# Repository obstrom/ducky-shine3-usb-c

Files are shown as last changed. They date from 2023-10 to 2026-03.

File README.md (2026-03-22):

# Ducky Shine3 USB-C Mod

Unofficial USB 2.0 Type C replacement module for the Ducky Shine3 (DK9008S3) mechanical keyboard first released in 2013.

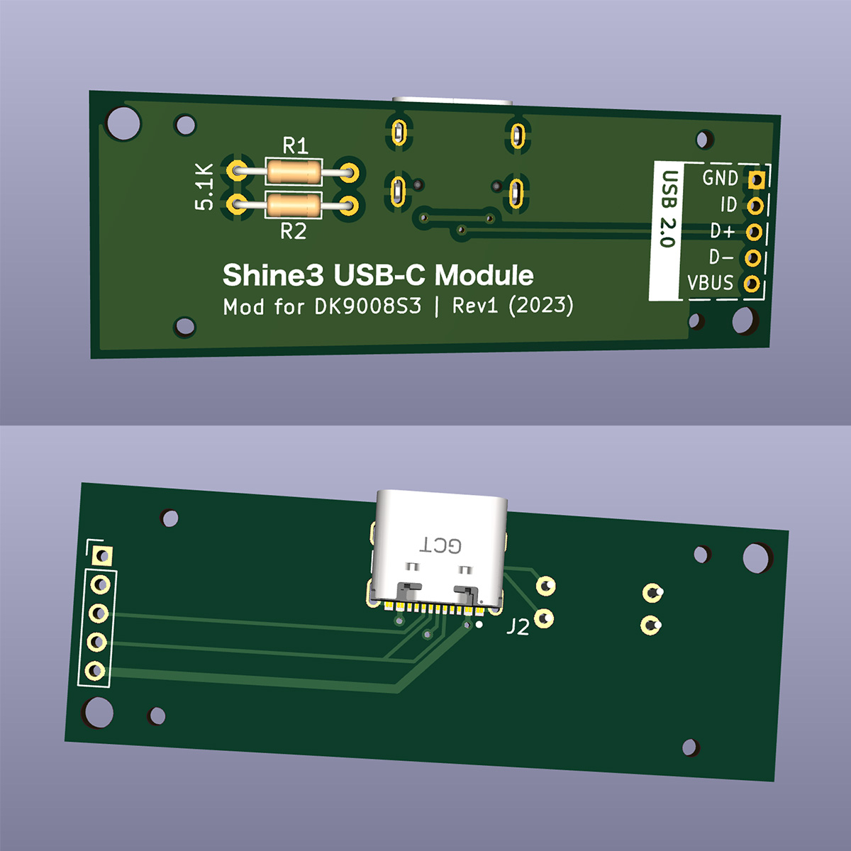
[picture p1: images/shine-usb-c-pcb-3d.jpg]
3D render from KiCad showing the finished PCB


This module is ment to replace the original USB 2.0 mini port on the Ducky Shine3, making it compatible with any USB C data cable.

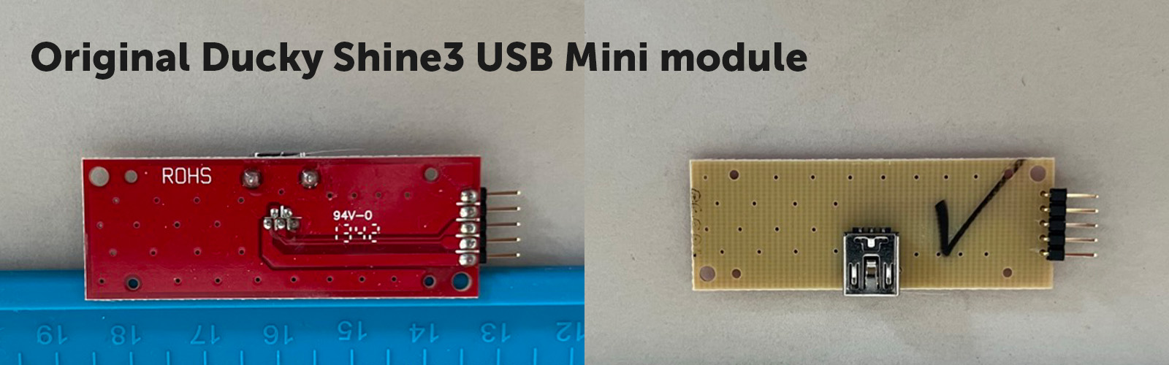
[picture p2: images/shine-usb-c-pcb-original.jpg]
Photo showing the original USB module


The project includes KiCad files. Feel free to edit and modify to your own needs. This also includes the gerber files if you want to order this PCB without doing any modifications. I've had one successful order of this PCB from JLCPCB without any issues.

To install this module you will have to slightly enlarge the USB connector opening in the hard plastic shell of the keyboard. I did this using my soldering iron and then tidied it up with a small file.

## KiCad

External footprint
* USB-C Connector: [USB4105-GF-A-060](https://www.snapeda.com/parts/USB4105-GF-A-060/GCT/view-part)

## PCB Specifications
| Specification | Value |
| --- | --- |
| Dimensions | 50 x 18 mm |
| Thickness | 1 mm |
| Layers | 2 |
| Copper | 1 oz (35μm) |
| Via covering  | Tented or filled |

## Parts
Parts needed to assemble the PCB.
| Amount | Part type | Part name |
| --- | --- | --- |
| 1 | USB2.0 Type C 16+8 connector | [USB4105-GF-A-060](https://www.digikey.se/sv/products/detail/gct/USB4105-GF-A-060/14559036) |
| 1 | 1x5 right angle connector | [2PH1R-05-UAA](https://www.digikey.se/en/products/detail/adam-tech/2PH1R-05-UA/9830981) |
| 2 | 5.1 kOhms resistor | [RNMF14FTC5K10](https://www.digikey.se/en/products/detail/stackpole-electronics-inc/RNMF14FTC5K10/2617363) |

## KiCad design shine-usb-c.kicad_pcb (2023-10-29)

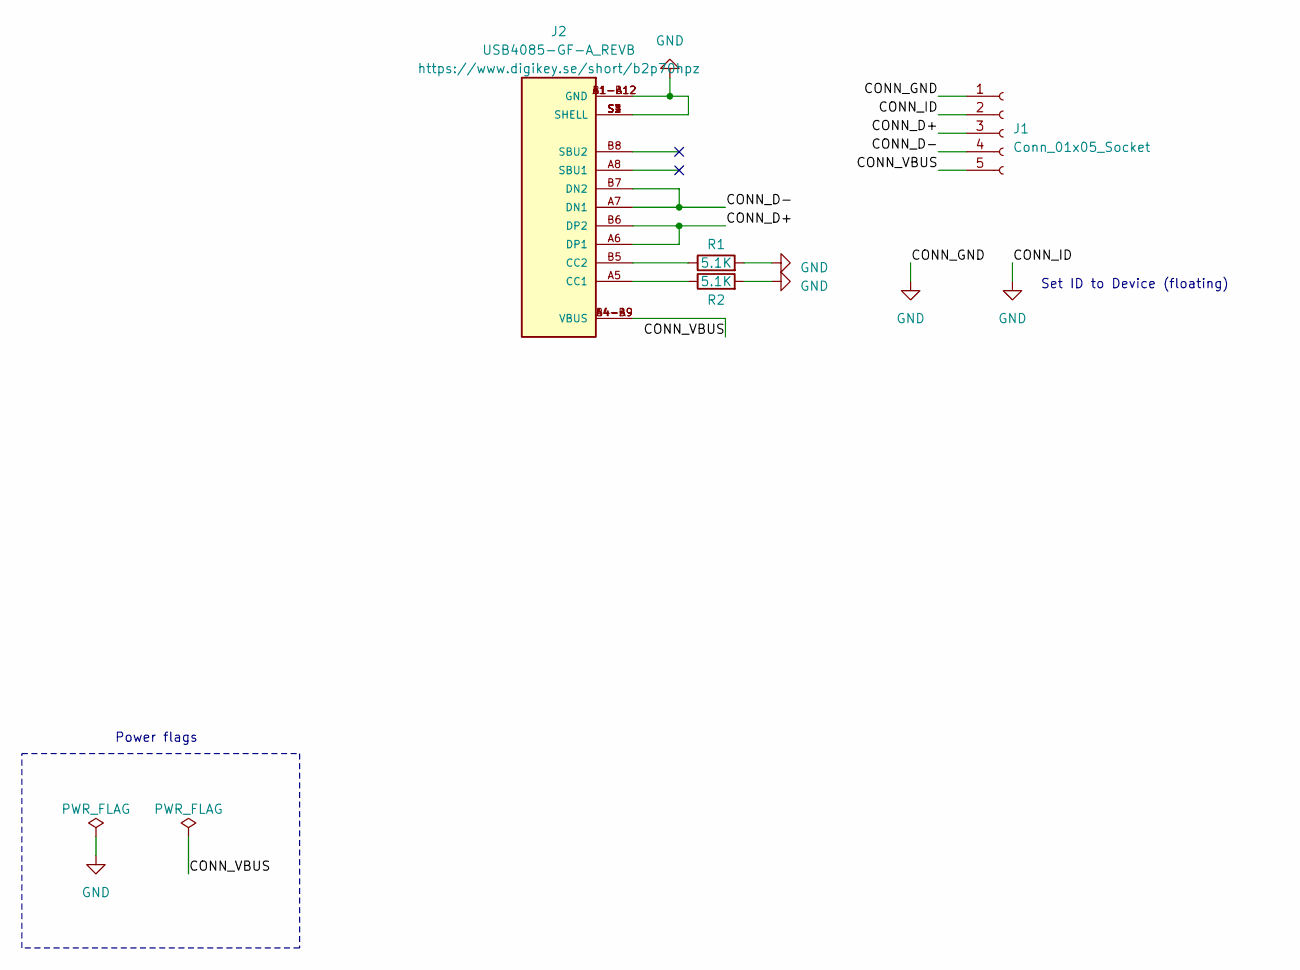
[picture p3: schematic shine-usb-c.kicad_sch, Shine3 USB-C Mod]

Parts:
J1: Conn_01x05_Socket; PinHeader_1x05_P2.00mm_Vertical
J2: USB4085-GF-A_REVB; USB4105-GF-A-060-MFG; PARTREV B
R1, R2: 5.1K; R_Axial_DIN0204_L3.6mm_D1.6mm_P7.62mm_Horizontal

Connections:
/CONN_D+: J1.3, J2.A6 (DP1), J2.B6 (DP2)
/CONN_D-: J1.4, J2.A7 (DN1), J2.B7 (DN2)
/CONN_VBUS: J1.5, J2.A4-B9 (VBUS), J2.B4-A9 (VBUS)
GND: J1.1, J1.2, J2.A1-B12 (GND), J2.B1-A12 (GND), J2.S1 (SHELL), J2.S2 (SHELL), J2.S3 (SHELL), J2.S4 (SHELL), R1.2, R2.2
unnamed: J2.A5 (CC1), R2.1
unnamed: J2.B5 (CC2), R1.1

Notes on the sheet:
Set ID to Device (floating)
Power flags

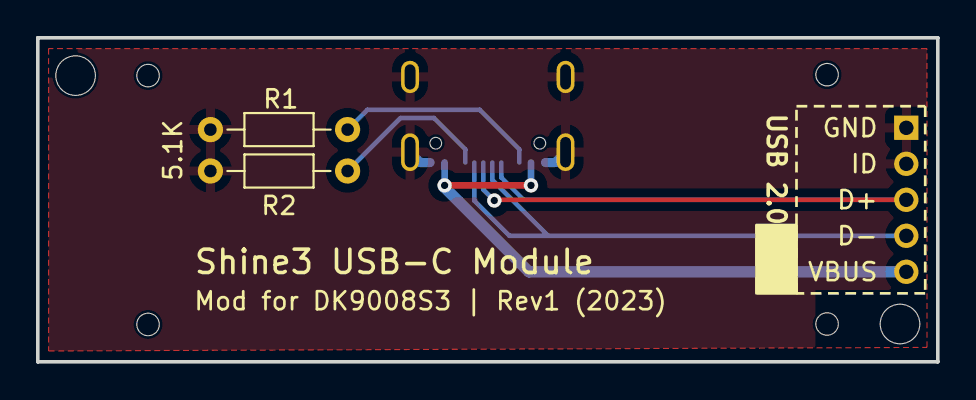
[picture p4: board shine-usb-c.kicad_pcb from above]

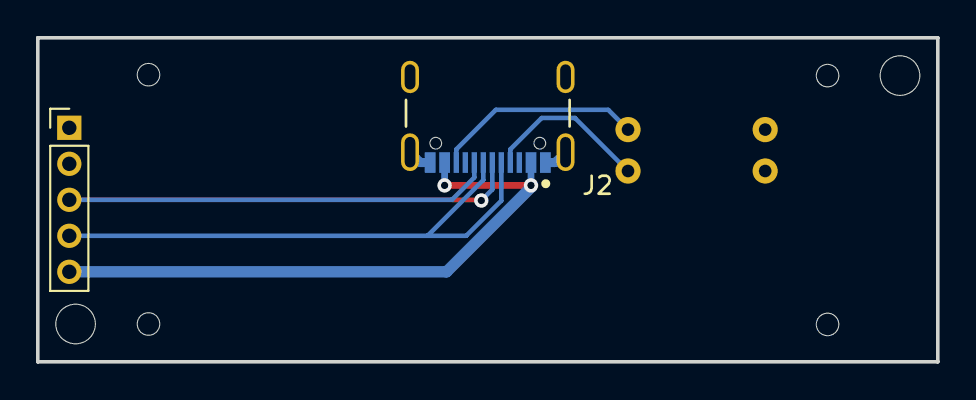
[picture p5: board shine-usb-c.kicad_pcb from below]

Board: 2 copper layers, 50.0 x 18.0 mm, 4 parts (2 on the bottom side), 6 nets.

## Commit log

2023-10-29 Add KiCad files
    [shine-usb-c.kicad_pcb, shine-usb-c.kicad_sch]
2023-10-29 Add gerber files
    [shine-usb-c-B_Cu.gbl, shine-usb-c-B_Mask.gbs, shine-usb-c-B_Paste.gbp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]
